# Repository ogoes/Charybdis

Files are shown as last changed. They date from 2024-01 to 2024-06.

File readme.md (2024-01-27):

# Charybdis

An ergonomic keyboard with integrated trackball.

Engineered to be a full mouse replacement solution with high-quality, custom-developed components.

There are 4x6, 3x6 "Mini" and 3x5 "Nano" versions.

Made to be used with the [Scylla](https://github.com/Bastardkb/Scylla), [TKB Mini](https://github.com/Bastardkb/TBK-Mini) or [Skeletyl](https://github.com/Bastardkb/Skeletyl) on the other half.





# Required components

## 3d prints - cases

The STL files are included in this Github repository, in the `files` folder.

Please find detailed instructions on how to print the case on the online instructions linked below.

Depending on which keyboard you are building, you will need different prints. There is a list in the table below - depending on the version number, the names will slightly vary. 

This repository is always updated with the latest version of the 3d models, and they are compatible with previous versions. For example, `charybdis.stl` might reference `charybdis3_v131.stl`.

**3d prints - 4x6**

| Description | File | Notes |
| --- | --- | --- |
| Right case | `4x6/charybdis.stl` | |
| Left case | | Download from the [Scylla repository](https://github.com/Bastardkb/Scylla) |
| Right plate | `4x6/plate_shield2.stl` | |
| Left plate | | Download from the [Scylla repository](https://github.com/Bastardkb/Scylla) |
| Adapter - top | `4x6/adapter_top.stl` | There is a different adapter for the 4x6 and 3x5, make sure to grab the one in the 4x6 folder ! |
| Adapter - bottom | `adapter_bottom.stl` | |
| Tent - right | `4x6/tent_alien.stl` | Optional 30 degree tent |
| Tent - left | `4x6/tent_alien.stl` | Optional 30 degree tent, mirror the file for left |

**3d prints - 3x6**

| Description | File | Notes |
| --- | --- | --- |
| Right case | `3x6 mini/Cmini.stl` | |
| Left case | | Download from the [TBK Mini repository](https://github.com/bastardkb/tbk-Mini), mirror the file for left |
| Right plate | `3x6 mini/plate.stl` | |
| Left plate | | Download from the [TBK Mini repository](https://github.com/bastardkb/tbk-Mini), mirror the file for left |
| Adapter - top | `3x5 nano/adapter_top.stl` | The 3x6 Mini uses the same top adapter as the 3x5 Nano |
| Adapter - bottom | `adapter_bottom.stl` | |
| Tent - right | `3x6 mini/tent.stl` | Optional 30 degree tent |
| Tent - left | `3x6 mini/tent.stl` | Optional 30 degree tent, mirror the file for left |

**3d prints - 3x5**

| Description | File | Notes |
| --- | --- | --- |
| Right case | `3x5 nano/charybdisnano.stl` | |
| Left case | | Download from the [Skeletyl repository](https://github.com/bastardkb/skeletyl), mirror the file for left |
| Right plate | `3x5 nano/plate.stl` | |
| Left plate | | Download from the [Skeletyl repository](https://github.com/bastardkb/skeletyl), mirror the file for left |
| Adapter - top | `3x5 nano/adapter_top.stl` | There is a different adapter for the 4x6 and 3x5, make sure to grab the one in the 3x5 folder ! |
| Adapter - bottom | `adapter_bottom.stl` | |
| Tent - right | `3x5 nano/tent/alien/tent.stl` | Optional tent* |
| Tent - left | `3x5 nano/tent/alien/tent.stl` | Optional tent, mirror the file for left* |

*If you are printing tents, there are multiple ones available for the Charybdis Nano. We recommend using the latest design which is the strongest and easiest to print - the alien version. There are both 30 and 15 degree versions available.

## Get a kit from BastardKB

You can get a full Kit, including case and all PCBs and electronics required on the shop:
https://bastardkb.com/

If you want to print the case yourself, you can also get just the electronics Kit.

## Electronic components

If you are sourcing the electronic components yourself, you can find a BOM in the [BOM](electronics_bom.md) file.

## Mods

There are some mods to add BTUs or ball bearings, check the *mods* folder.



# Build guide

You can find detailed instruction on the online documentation linked below.

# Links

- Discord: https://bastardkb.com/discord
- Website: https://bastardkb.com/
- Docs: https://docs.bastardkb.com

# Support me on Patreon

If you like the keyboard, please consider helping me with Patreon: https://www.patreon.com/bastardkb

I post regular updates and hindsight on my work. I work full time on keyboard innovation, and this helps a lot !

# License 

This work is licensed under a Creative Commons Attribution-NonCommercial-ShareAlike 4.0 International License.

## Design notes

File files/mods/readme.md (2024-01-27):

# Table of contents

- [Table of contents](#table-of-contents)
- [Charybdis - generic](#charybdis---generic)
  - [BTU Mod](#btu-mod)
  - [Veichu Bearing Mod](#veichu-bearing-mod)
  - [Printable BTU Mod](#printable-btu-mod)
  - [Printable BTU Mod - with screws](#printable-btu-mod---with-screws)
    - [Upgraded inserts for the Printable BTU Mod](#upgraded-inserts-for-the-printable-btu-mod)
  - [Trackpad mod for the Charybdis](#trackpad-mod-for-the-charybdis)
  - [Alternative sensors](#alternative-sensors)
- [Charybdis](#charybdis)
  - [Palm Rest](#palm-rest)
    - [Straight mod](#straight-mod)
    - [Slope mod](#slope-mod)
  - [Modular adjustable tenting stand for Charybdis/Scylla](#modular-adjustable-tenting-stand-for-charybdisscylla)
    - [Base](#base)
    - [Variant with wrist wrest](#variant-with-wrist-wrest)
- [Charybdis Nano](#charybdis-nano)
  - [Midglow PCB for the Charybdis Nano tents](#midglow-pcb-for-the-charybdis-nano-tents)
  - [Trackpad mod for the Charybdis Nano organic tents](#trackpad-mod-for-the-charybdis-nano-organic-tents)
  - [Chair Mount Plate](#chair-mount-plate)
  - [Modular Thumb Cluster](#modular-thumb-cluster)
  - [Trackball cover - Sensor\_cover](#trackball-cover---sensor_cover)
  - [Trackball cover - Ball\_cover](#trackball-cover---ball_cover)

# Charybdis - generic

## BTU Mod

Very smooth, *very expensive*.



If you want to use BTUs rather than bearings, you will need to print the bottom adapter btu model, and source some 4.8mm BTUs.

The adapter model is designed around those: https://nl.rs-online.com/web/p/ball-transfer-units/7431408/.

Print the file in the `btu` folder.

## Veichu Bearing Mod

The veichu bearings are a cheaper alternative to the BTUs. 

They need to be press-fitted into the 3d print, as they have no screws.

Print the file in the `veichu` folder.

## Printable BTU Mod

Pretty smooth, *less expensive*.



You can use this option if you don't want to use bearings or buy the expensive BTU part. 
There are files for 3.175mm (1/8"), and 2.5mm balls, you will need to print 3 of them as well as the bottom btu model. 

Press the balls into the model then insert them into the bottom btu model.

Links:
- [Bottom BTU Model](printable-btu-screws/bottom.stl)
- [Inserts](printable-btu) (choose either 3.175mm or 2.5mm)

## Printable BTU Mod - with screws

Uses screws instead of pression fit to hold the ball inserts in the model. You will need M3 4mm screws.

Two versions : with 3.175mm balls, and 4mm balls.

Print:
- [Bottom BTU Model](printable-btu-screws/bottom.stl)
- [3.175mm insert](printable-btu-screws/balls-3.1mm/inserts.stl)
- [4mm insert](printable-btu-screws/balls-4mm/inserts.stl)

### Upgraded inserts for the Printable BTU Mod

A bit taller of inserts, at 5mm tall, and a little more pronounced recess for the bearing ball.

The snap of the bearing ball is a little less intense as a result and gives more surface angle for the ball to rest on, resulting in a more secure seat for the ball.

Print:
- [Bottom BTU Model](printable-btu-screws/bottom.stl)
- [tall-inserts.stl](printable-btu-screws/balls-3.1mm/tall-inserts.stl)

Print and snap off supports. Sand the burrs if necessary.

## Trackpad mod for the Charybdis

Print the 2 files in the `mods/trackpad/trackball-holder` folder. Install in place of the trackball holder.
Connect the trackpad to sda, scl, vcc, gnd.

Required hardware:

| Part name | Amount | Link |
| --- | --- | --- |
| M4 8mm Torx Screw | 1 | Conrad |
| M4 screw insert, M4 X D6.0 X L5.0 | 1 | https://fr.aliexpress.com/item/4000232925592.html?spm=a2g0s.12269583.0.0.6aef4f282LZO4v |



## Alternative sensors

There are files in the [`bottom_adapter_alternative_sensors`](./bottom_adapter_alternative_sensors/README.md) directory to accomodate PMW3389 and ADNS9800 sensor PCBs.

# Charybdis

## Palm Rest 

Those palm rests are to be placed at the bottom of the keyboard, to support your palms. There are both sloped and straight versions.

For each version, there are 3 files:

- `STL`: for 3D printing
- `DWG`: for laser cutting
- `SLDPRT`: solidworks source file

The files for the Charybdis and Scylla are different:
- For the Charybdis, use the files in [4x6-palm-rest](4x6-palm-rest)
- For the Scylla, use the files from the [palm rest folder](https://github.com/Bastardkb/Scylla/tree/main/files/palm-rest)

### Straight mod


### Slope mod


## Modular adjustable tenting stand for Charybdis/Scylla

Details: [tenting-stand-with-wrist-pads/readme.md](tenting-stand-with-wrist-pads/readme.md)

### Base

tenting stand

### Variant with wrist wrest

tending stand with wrist wrests

# Charybdis Nano

## Midglow PCB for the Charybdis Nano tents

Check repo here: https://github.com/Bastardkb/Charybdis-nano-tent-glow



**Please note only the organic tent is compatible with the midglow rgb !**

## Trackpad mod for the Charybdis Nano organic tents

Print the 2 files in the `mods/trackpad/3x5-tent` folder. Install on the organic tent, connect to sda, scl, vcc, gnd.

Required hardware:

| Part name | Amount | Link |
| --- | --- | --- |
| M4 8mm Torx Screw | 5 | Conrad |
| M4 screw insert, M4 X D6.0 X L5.0 | 5 | https://fr.aliexpress.com/item/4000232925592.html?spm=a2g0s.12269583.0.0.6aef4f282LZO4v |



## Chair Mount Plate
Alternate bottom plate for mounting to a chair or desk using standard camera mounting equipment. Fits 1/4 inch mounting bolt (1/4-20 UNC).
Found in the `3x5 nano/chairMountPlate` folder.  



## Modular Thumb Cluster
Based on the 3x5 Skeletyl/Charybdis Nano. This has a slightly modified plate, a 3 switch thumb cluster (ala Skeletyl), a 2 switch thumb cluster with the mount for a trackball/trackpad (ala Charybdis Nano) and a modified main body

Note: Below picture uses a standard Skeletyl main body that was cut to make room for the modular thumb cluster but a purpose printed main body should give better results!

| Part name | Amount | Link |
| --- | --- | --- |
| M4 8mm Torx Screw | 2 | Conrad |
| M4 screw insert, M4 X D6.0 X L5.0 | 2 | https://fr.aliexpress.com/item/4000232925592.html?spm=a2g0s.12269583.0.0.6aef4f282LZO4v |



## Trackball cover - Sensor_cover

A trackball sensor cover to be used in combination with the original bottom cover. Protects the sensor from outside elements.



File is in [trackball-cover](trackball-cover).

## Trackball cover - Ball_cover

Use in place of adapter_v2_top_v75.stl to prevent balls from falling.
Adjusting the height for [printable-btu-screws](printable-btu-screws).
Rotating the ball may be difficult at first, but you will get used to it by putting it on and taking it off a few times and rotating it.
The screw holes of this part have an inner diameter (5mm) that allows you to glue M3 (x5x5) threaded inserts.

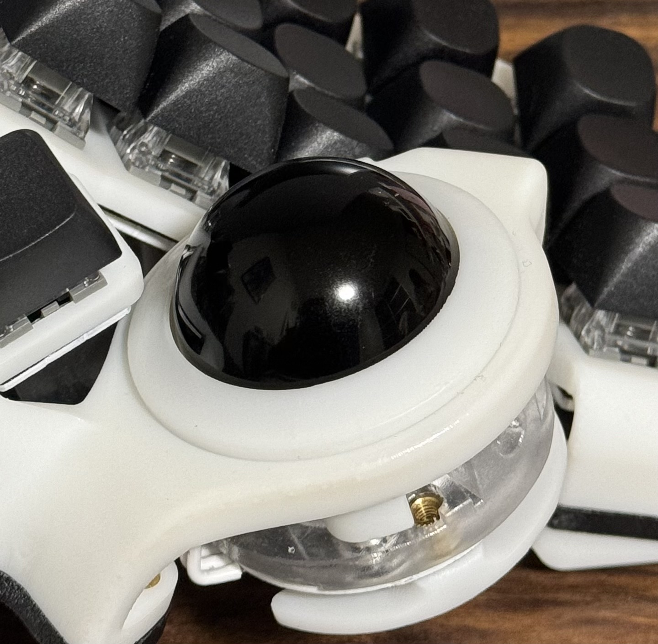
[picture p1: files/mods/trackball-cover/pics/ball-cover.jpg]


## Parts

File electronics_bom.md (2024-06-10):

| Part name | Amount (4x6) | Amount (3x6) | Amount (3x5) | Link |
| --- | --- | --- | --- | --- |
| Sensor PCB | 1 | 1 | 1 | <https://github.com/Bastardkb/charybdis-pmw-sensor> |
| Splinky | 2 | 2 | 2 | <https://github.com/bastardkb/splinky> |
| Splinky adapter for the Charybdis | 2 | 2 | 2 | <https://github.com/Bastardkb/Elite-C-holder> |
| Cables | | | | 28 AWG recommended |
| Audio jack, SMD | 2 | 2 | 2 | |
| Button, 4x4x1.5 | 2 | 2 | 2 | <https://www.aliexpress.com/item/1005001304569553.html?spm=a2g0s.9042311.0.0.27424c4dDwgcp7> |
| Sensor PCB | 1 | 1 | 1 | see details below |
| Bearing, MR63-3x6x2.5mm | 3 | 3 | 3 | |
| Flexible PCB for the plate (4x6)  | 2 | 0 | 0 | <https://github.com/Bastardkb/Scylla-PCB-Plate> |
| Flexible PCB for the plate (3x6)  | 0 | 2 | 0 | <https://github.com/Bastardkb/TBK-Mini-PCB-plate> |
| Flexible PCB for the plate (3x5)  | 0 | 0 | 2 | <https://github.com/Bastardkb/Skeletyl-PCB-plate> |
| Flexible PCB for the thumbs | 1 | 1 | 1 | <https://github.com/Bastardkb/PCB_thumbs_Charybdis> |
| Flexible PCB for the thumbs (4x6) | 1 | 0 | 0 | <https://github.com/Bastardkb/Scylla-PCB-thumb-cluster> |
| Flexible PCB for the thumbs (3x5) | 0 | 1 | 1 | <https://github.com/Bastardkb/TBK-Mini-PCB-thumb-cluster> |
| SOD123 Diodes | 8 | 42 | 35 | |
| BAT54C Diodes | 24 | 0 | 0 | |
| M4 8mm Torx Screw | 16 | 12 | 12 | Conrad |
| M4 screw insert, M4 X D6.0 X L5.0 | 16 | 12 | 12 | <https://fr.aliexpress.com/item/4000232925592.html?spm=a2g0s.12269583.0.0.6aef4f282LZO4v> |
| Screws, M3 8mm Torx | 8 | 8 | 8 | |
| Heated screw insert, M3x5x5 | 5 | 5 | 5 | |

If you want RGB, you will also need:

| Part name | Amount (4x6) | Amount (3x6) | Amount (3x5) | Link |
| --- | --- | --- | --- | --- |
| SK6812 Mini-E LEDs | 58 | 42 | 35 | Aliexpress |
| Capacitor, 1uF, size 1206 | 4 | 4 | 4 | |
| Resistor, 330Ohms, size 1206 | 4 | 4 | 4 | |
| Wires | | | | 28 AWG recommended, Black, Red, Color |
| Ribbon cables Flexstrip | 6 | 6 | 6 | |

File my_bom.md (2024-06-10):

# PCBs

| Part name | Amount | Link | Price |
| --- | --- | --- | --- |
| Flexible PCB for the plate | 2 | <https://github.com/Bastardkb/TBK-Mini-PCB-plate> | 25.50 Euro / 5 |
| Flexible PCB for the right thumb | 1 | <https://github.com/Bastardkb/PCB_thumbs_Charybdis> | 2 Euro / 5 |
| Flexible PCB for the left thumb  | 1 | <https://github.com/Bastardkb/TBK-Mini-PCB-thumb-cluster> | 3.5 Euro / 5 |
| PMW PCB breakout (assembled) | 1 | <https://github.com/victorlucachi/charybdis-pmw3610-breakout> | 16.5 Euro / 5  |
| nice!nano PCB breakout | 2 | <https://github.com/victorlucachi/Elite-C-holder> | 3.5 Euro / 5 |

-> 70 Euro (16 Euro shipping) (for 5 keyboards)

# Electronics

| Part name | Amount | Link | Price |
| --- | --- | --- | --- |
| nice!nano v2 | 2 | <https://kriscables.com/product/nicenano/> | 56 Euro |
| Li-Po Battery 3.7v 110mah | 2 | <https://kriscables.com/product/li-po-battery-3-7v-110mah/> | 18 Euro |
| Mill Max Socket Pins | 2x24 | <https://kriscables.com/product/mill-max-socket-pins/> | 8 Euro  |
| Power Switch | 2 | <https://kriscables.com/product/msk-12c02-power-switch/> | 1 Euro  |
| Button, 4x4x1.5 | 2 | <https://www.aliexpress.com/item/1005001304569553.html?spm=a2g0s.9042311.0.0.27424c4dDwgcp7> | 2 Euro  |
| SOD123 Diodes | 42 | <https://de.aliexpress.com/item/32854082527.html?spm=a2g0o.73bc5c5f5RAo62> | 11 Euro |
| PMW3610 | 1 | <https://www.aliexpress.com/item/33032642745.html?spm=a2g0o.5.66271802znmdgw> | 10 Euro |
| Key Switches | 41 | <https://www.aliexpress.com/item/1005006252612688.html?spm=a2g0o.22.66271802znmdgw> | 13 Euro |
| JST PH 2.0 cable and jack | 2 | <https://www.ebay.de/itm/183607216953?var=691029636494> | 6 Euro  |
| Cables | | 28 AWG recommended |

-> 125 Euro

# 3D Prints

| Description | File | Notes |
| --- | --- | --- |
| Right case | `CMini_v1_v11-right.3mf` | |
| Left case | `adapter_bottom.stl` | mirror the file for left |
| Right plate | `plate_v1_v11-right.stl` | |
| Left plate | `plate_v3_v29-left.stl` | mirror the file for left |
| Adapter - top | `adapter_v2_top_v75.stl` | The 3x6 Mini uses the same top adapter as the 3x5 Nano |
| Adapter - bottom | `adapter_v4_bottom_v17.stl` | |
| Tent - right | `tent_v2_v57-right.3mf` | Optional 30 degree tent |
| Tent - left | `tent_v2_v57-left.3mf` | Optional 30 degree tent, mirror the file for left |
| PMW Adapter | `pmw3610_charybdis_adapter.stl` | Adapter that secures the LM18-LSI sensor lens, for the PMW3610 sensor |

-> roughly 20 Euro

# Others

| Part name | Amount | Link | Price |
| --- | --- | --- | --- |
| DSA Key Caps | 41 | <https://www.aliexpress.com/item/1005004405721819.html?spm=a2g0o.17.66271802znmdgw> | 25 Euro |
| Bearing, MR63-3x6x2.5mm | 3 | | 8 Euro  |
| M4 screw insert, M4 X D6.0 X L5.0 | 12 | <https://fr.aliexpress.com/item/4000232925592.html?spm=a2g0s.12269583.0.0.6aef4f282LZO4v> | 3 Euro  |
| M4 8mm Torx Screw | 12 | Conrad | 3 Euro  |
| Heated screw insert, M3x5x5 | 5 | | 3 Euro  |
| Screws, M3 8mm Torx | 8 | | 2 Euro  |
| Perixx Trackball 34mm | 1 | <https://www.amazon.de/-/en/dp/B07BDF725X?ref=ppx_yo2ov_dt_b_product_details&th=1> | 12 Euro |

-> 56 Euro

--> Total: ± 180 Euro

TODO:

- buy screws with flat head
- design and print adapter for the sensor

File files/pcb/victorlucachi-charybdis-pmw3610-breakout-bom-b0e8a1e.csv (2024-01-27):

Designator | Footprint | Quantity | Value | LCSC Part #
 |  | 1
C1 | 0603 | 1 | 10n | C19666
C2, C7 | 0603 | 2 | 100n | C19666
C3 | 0603 | 1 | 3.3u/16V | C19666
C4 | 0603 | 1 | 0.1u | C14663
C5 | 0603 | 1 | 1u | C15849
C6 | 0603 | 1 | 100n (X7R) | C19666
C8 | 0603 | 1 | 10u (X7R) | C19666
C9 | 0603 | 1 | 10n (X7R) | C19666
J1 | PinHeader_1x06_P2.54mm_Vertical | 1 | Conn_01x06
R1 | 0603 | 1 | 2M
U1 | SOT-23-5 | 1 | TCR2EF19 | C146366

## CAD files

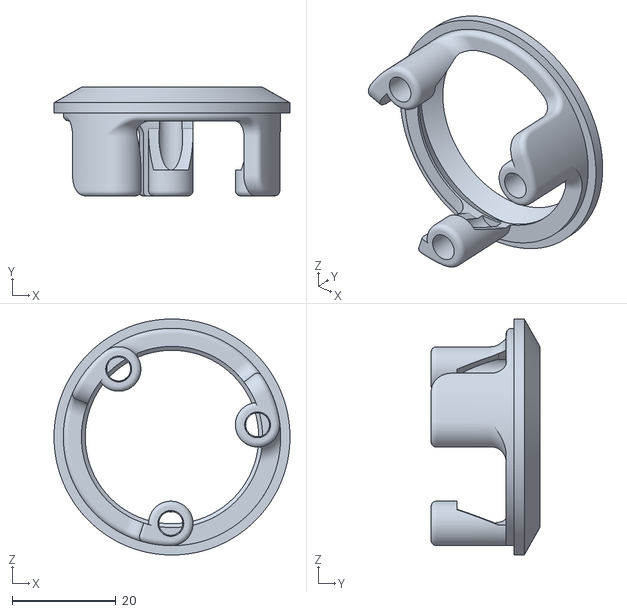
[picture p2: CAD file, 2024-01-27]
files/mods/trackball-cover/Ball_cover_resin_5mm.stl
45.6 x 21.0 x 45.6

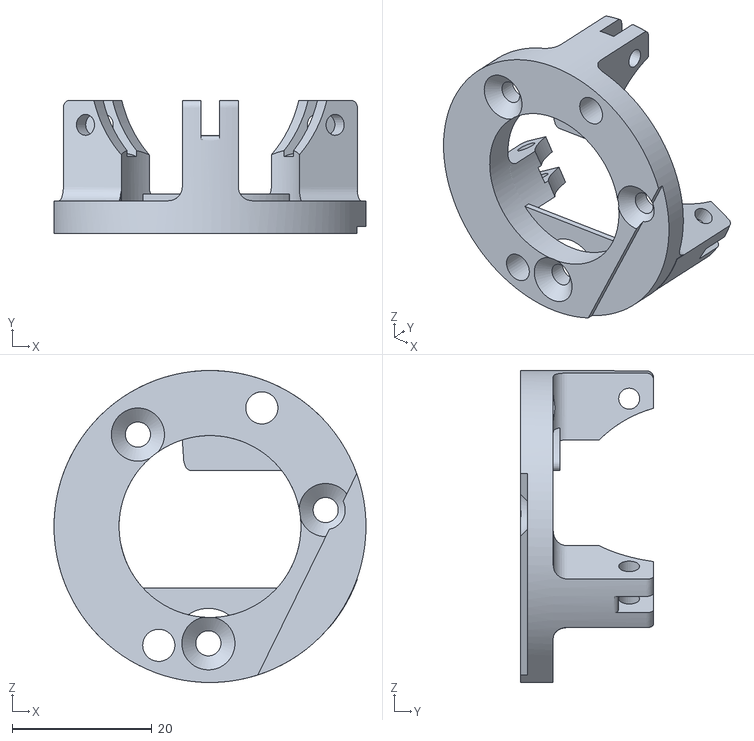
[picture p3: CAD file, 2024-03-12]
my-files/3D/adapter_v4_bottom_v17.stl
44.6 x 19.1 x 44.6

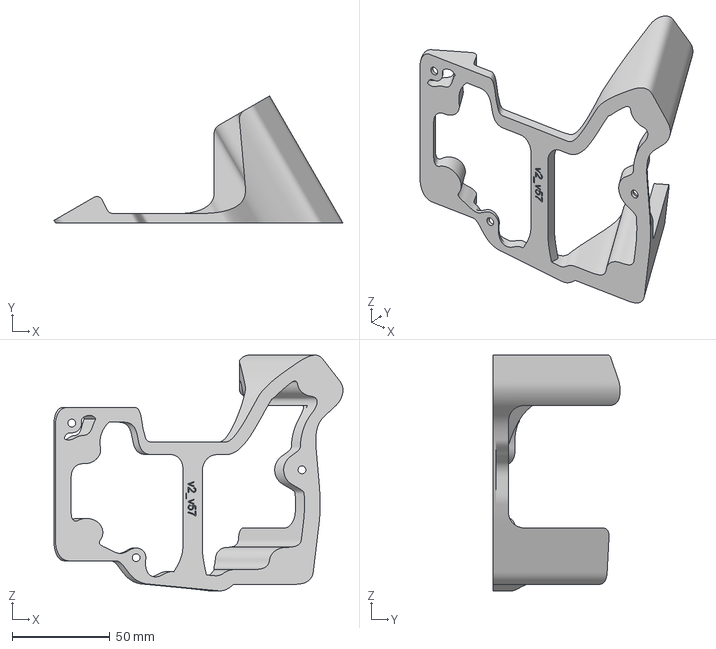
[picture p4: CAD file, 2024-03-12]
my-files/3D/tent_v2_v57-left.3mf
148.2 x 65.2 x 120.9 mm

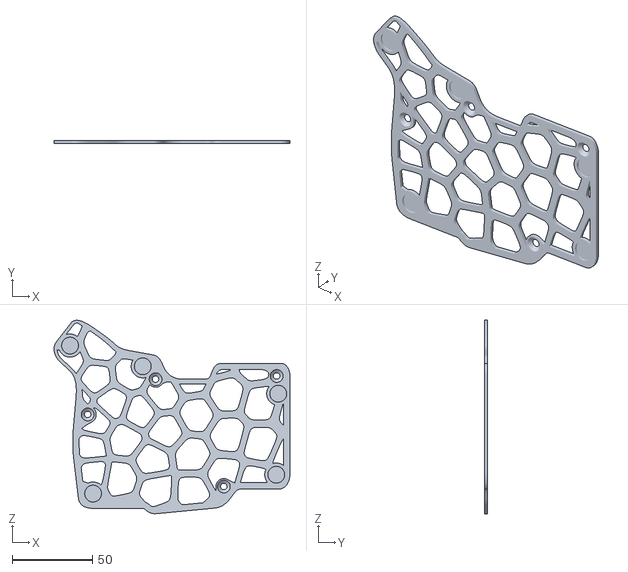
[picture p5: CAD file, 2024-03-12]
my-files/3D/plate_v3_v29-left.stl
147.4 x 2.00 x 120.9

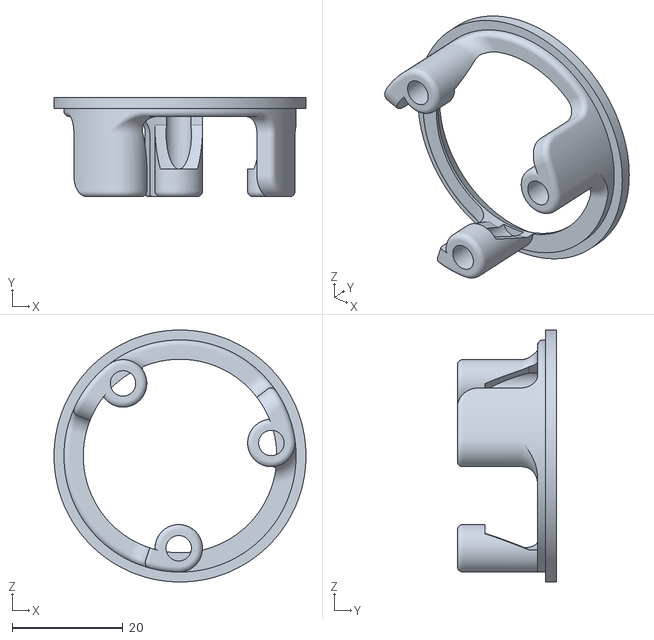
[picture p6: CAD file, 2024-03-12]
my-files/3D/adapter_v2_top_v75.stl
45.6 x 18.0 x 45.6

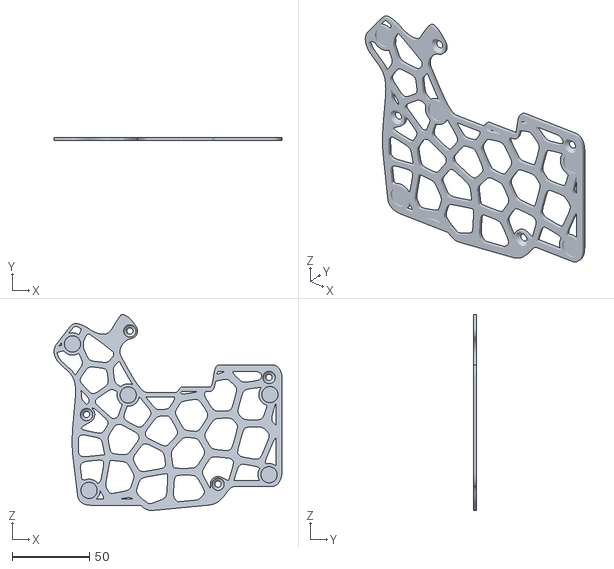
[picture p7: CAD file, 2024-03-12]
my-files/3D/plate_v1_v11-right.stl
147.4 x 2.00 x 126.7

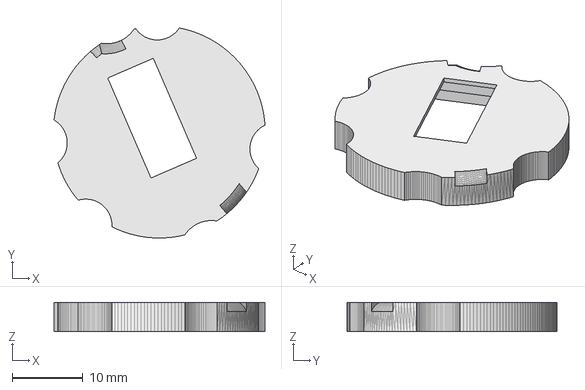
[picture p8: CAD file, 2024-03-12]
my-files/3D/my_pmw_adapter.FCStd
29.7 x 29.6 x 4.10 mm

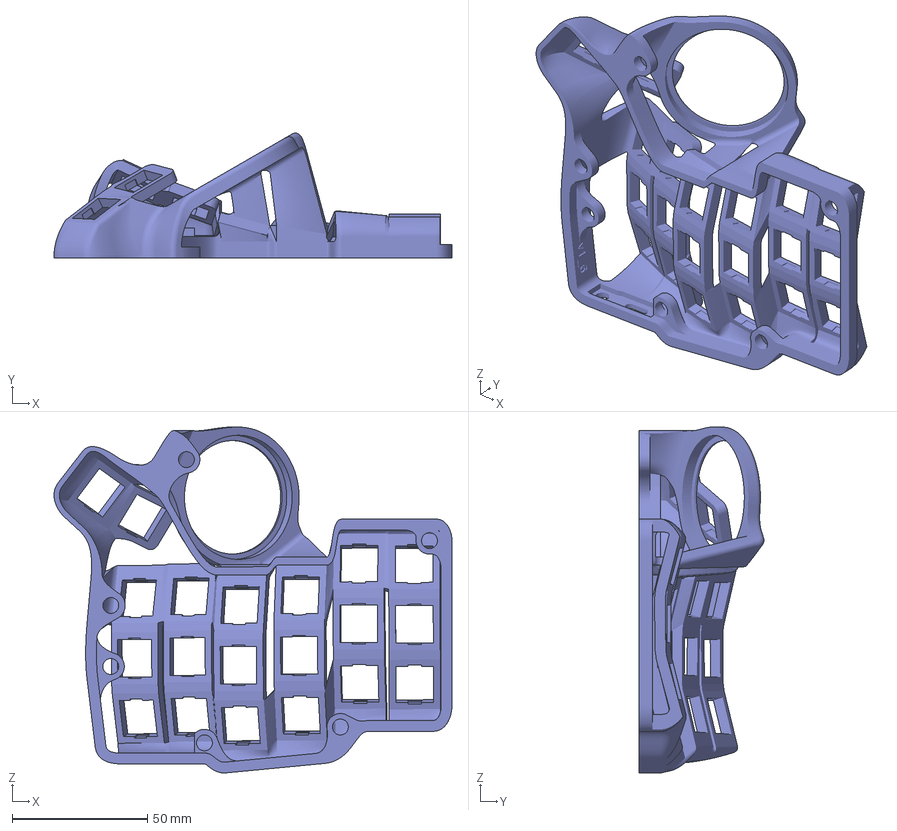
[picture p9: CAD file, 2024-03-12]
my-files/3D/CMini_v1_v11-right.3mf
147.4 x 46.2 x 128.1 mm

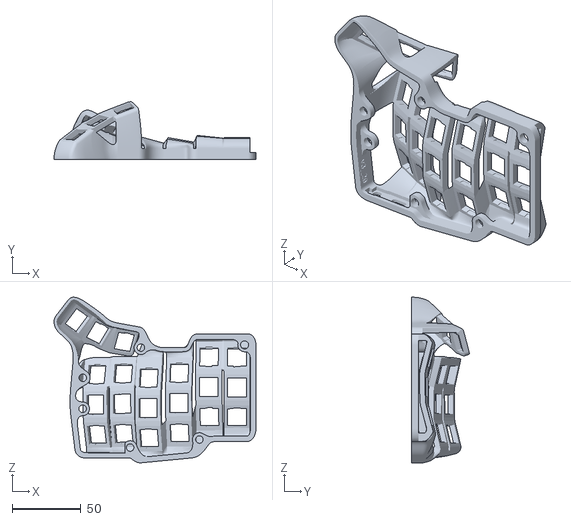
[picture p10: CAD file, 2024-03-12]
my-files/3D/case_v3_v29-left.stl
147.4 x 42.0 x 120.9

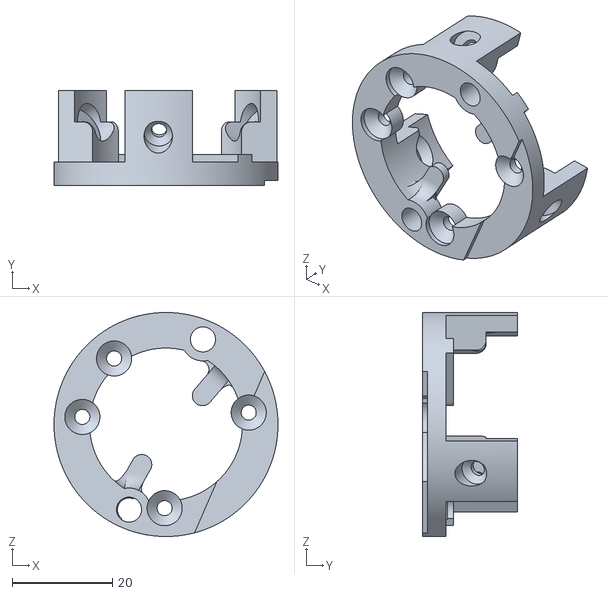
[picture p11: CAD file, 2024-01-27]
files/mods/printable-btu-screws/bottom_resin_5mm.stl
44.7 x 19.0 x 44.7

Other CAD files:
my-files/3D/pmw3610_charybdis_adapter.stl

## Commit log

2024-01-27 add required PCB (gerber and bom) files
    [victorlucachi-charybdis-pmw3610-breakout-bom-b0e8a1e.csv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]
2024-01-27 add custom bom
2024-01-27 move my files to a separate folder
    [victorlucachi-charybdis-pmw3610-breakout-bom-b0e8a1e.csv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]
2024-03-12 update files and bom
    [CMini_v1_v11-right.3mf, adapter_v2_top_v75.stl, adapter_v4_bottom_v17.stl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]
2024-06-10 rebase original repo
    [victorlucachi-charybdis-pmw3610-breakout-bom-b0e8a1e.csv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]
2024-06-10 format bom
